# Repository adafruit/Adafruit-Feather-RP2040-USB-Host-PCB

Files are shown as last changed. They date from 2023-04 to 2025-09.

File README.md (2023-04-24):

## Adafruit Feather RP2040 with USB Host PCB

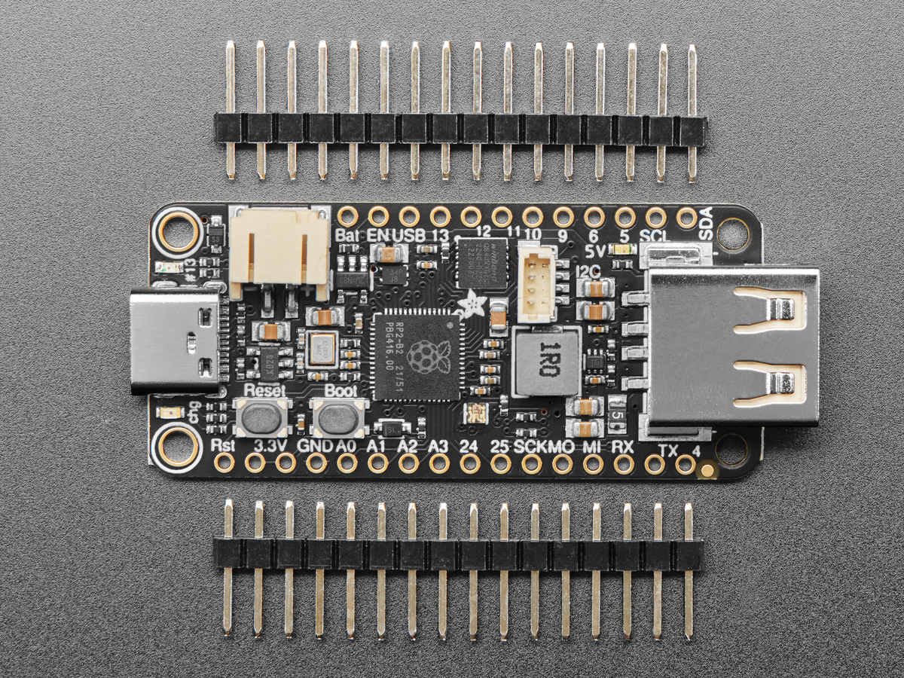
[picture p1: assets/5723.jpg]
<a href="http://www.adafruit.com/products/5723"><br/>
Click here to purchase one from the Adafruit shop</a>

PCB files for the Adafruit Feather RP2040 with USB Host. 

Format is EagleCAD schematic and board layout
* https://www.adafruit.com/product/5723

### Description

You're probably really used to microcontroller boards with USB, but what about a dev board with two? Two is more than one, so that makes it twice as good! And the Adafruit Feather RP2040 with USB Host is definitely double-the-fun of our other Feather RP2040 boards, with a USB Type A port on the end for connecting USB devices to. 

Now you might be thinking "hey waitaminute, the RP2040 doesn't have two USB port peripherals???" and you'd be correct! But what it does have is a nifty PIO peripheral that can be (ab)used to emulate a USB host peripheral. You get to keep the main USB port for uploading, debugging, and data communication, while at the same time sending and receiving data to just-about-any USB device. [This work is originally by sekigon on GitHub](https://github.com/sekigon-gonnoc/Pico-PIO-USB), and if you're using Pico SDK that's still the recommended library to use.

Currently, support for the USB Host peripheral is only in Arduino. So check out the [TinyUSB 'dual role' examples](https://github.com/adafruit/Adafruit_TinyUSB_Arduino/tree/master/examples/DualRole) for some things you can do! For example, [datalogging to a USB Key](https://github.com/adafruit/Adafruit_TinyUSB_Arduino/tree/master/examples/DualRole/MassStorage/msc_data_logger). Or [reading from another device/microcontroller that has USB CDC serial interface](https://github.com/adafruit/Adafruit_TinyUSB_Arduino/tree/master/examples/DualRole/CDC/serial_host_bridge). Or [creating an HID re-mapper](https://github.com/adafruit/Adafruit_TinyUSB_Arduino/tree/master/examples/DualRole/HID/hid_remapper). Or [connecting to weird devices that require firmware-updates like the Cypress EZ-USB based Intellikeys](https://github.com/adafruit/Adafruit_IntelliKeys) communications board.

Note that this is definitely a firmware hack: you will need to dedicate the second ARM core and both PIO peripherals to just handling the USB messages, but we find that it does work fairly well, or at least as well as most microcontroller's USB Host peripherals!

We also include a 1 Amp boost converter based on the TPS61023 so you can run from Lipo battery and get a nice clean 5V output for the USB devices. The booster has the enable pin tied to one of the extra GPIO on the RP2040 so power can be manually turned on and off to hard-reset whatever is connected.

At the Feather's heart is an RP2040 chip, clocked at 133 MHz and at 3.3V logic, the same one used in the Raspberry Pi Pico. This chip has a whopping 8MB of onboard QSPI FLASH and 264K of RAM!  There's even room left over for a STEMMA QT connector for plug-and-play of I2C devices!

To make it easy to use for portable projects, we added a connector for any of our 3.7V Lithium polymer batteries and built-in battery charging. You don't need a battery, it will run just fine straight from the USB Type C connector. But, if you do have a battery, you can take it on the go, then plug in the USB to recharge. The Feather will automatically switch over to USB power when it's available.

Here're some handy specs! You get:

* Measures 2.0" x 0.9" x 0.28" (50.8mm x 22.8mm x 7mm) without headers soldered in
* Light as a (large?) feather - 6.3 grams
* RP2040 32-bit Cortex M0+ dual core running at ~133 MHz @ 3.3V logic and power
* 264 KB RAM
* 8 MB SPI FLASH chip for storing files and CircuitPython/MicroPython code storage. No EEPROM
* Tons of GPIO! 21 x GPIO pins with following capabilities:
* Four 12-bit ADCs (one more than Pico)
* Two I2C, Two SPI, and two UART peripherals, we label one for the 'main' interface in standard Feather locations
* 16 x PWM outputs - for servos, LEDs, etc
* Built-in 200mA+ lipoly charger with charging status indicator LED
* Pin #13 red LED for general purpose blinking
* RGB NeoPixel for full-color indication.
* On-board STEMMA QT connector that lets you quickly connect any Qwiic, STEMMA QT or Grove I2C devices with no soldering!
* Both Reset button and Bootloader select button for quick restarts (no unplugging-replugging to relaunch code)
* USB Type C connector lets you access built-in ROM USB bootloader and serial port debugging
* USB Type A connector for USB host capability. D+ on GPIO 16, D- on GPIO 17
* 5V Boost converter, up to 1 Amp peak output for USB peripheral power, with 500mA resettable fuse. Enable on GPIO 18. 
* 3.3V Power/enable pin
* 4 mounting holes
* 12 MHz crystal for perfect timing.
* 3.3V regulator with 500mA peak current output

### License

Adafruit invests time and resources providing this open source design, please support Adafruit and open-source hardware by purchasing products from [Adafruit](https://www.adafruit.com)!

Designed by Limor Fried/Ladyada for Adafruit Industries.

Creative Commons Attribution/Share-Alike, all text above must be included in any redistribution. 
See license.txt for additional details.

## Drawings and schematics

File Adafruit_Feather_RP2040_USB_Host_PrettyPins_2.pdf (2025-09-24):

## Power GND

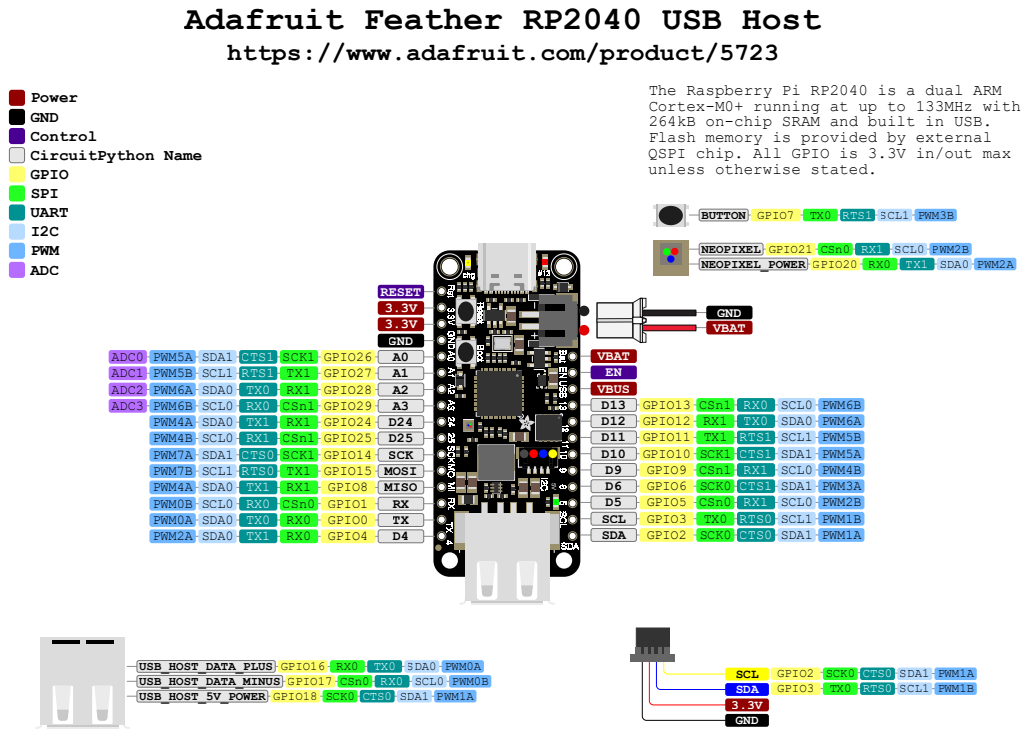
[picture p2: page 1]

Adafruit Feather RP2040 USB Host
https://www.adafruit.com/product/5723

The Raspberry Pi RP2040 is a dual ARM
Cortex-M0+ running at up to 133MHz with
264kB on-chip SRAM and built in USB.
Flash memory is provided by external
QSPI chip. All GPIO is 3.3V in/out max
unless otherwise stated.

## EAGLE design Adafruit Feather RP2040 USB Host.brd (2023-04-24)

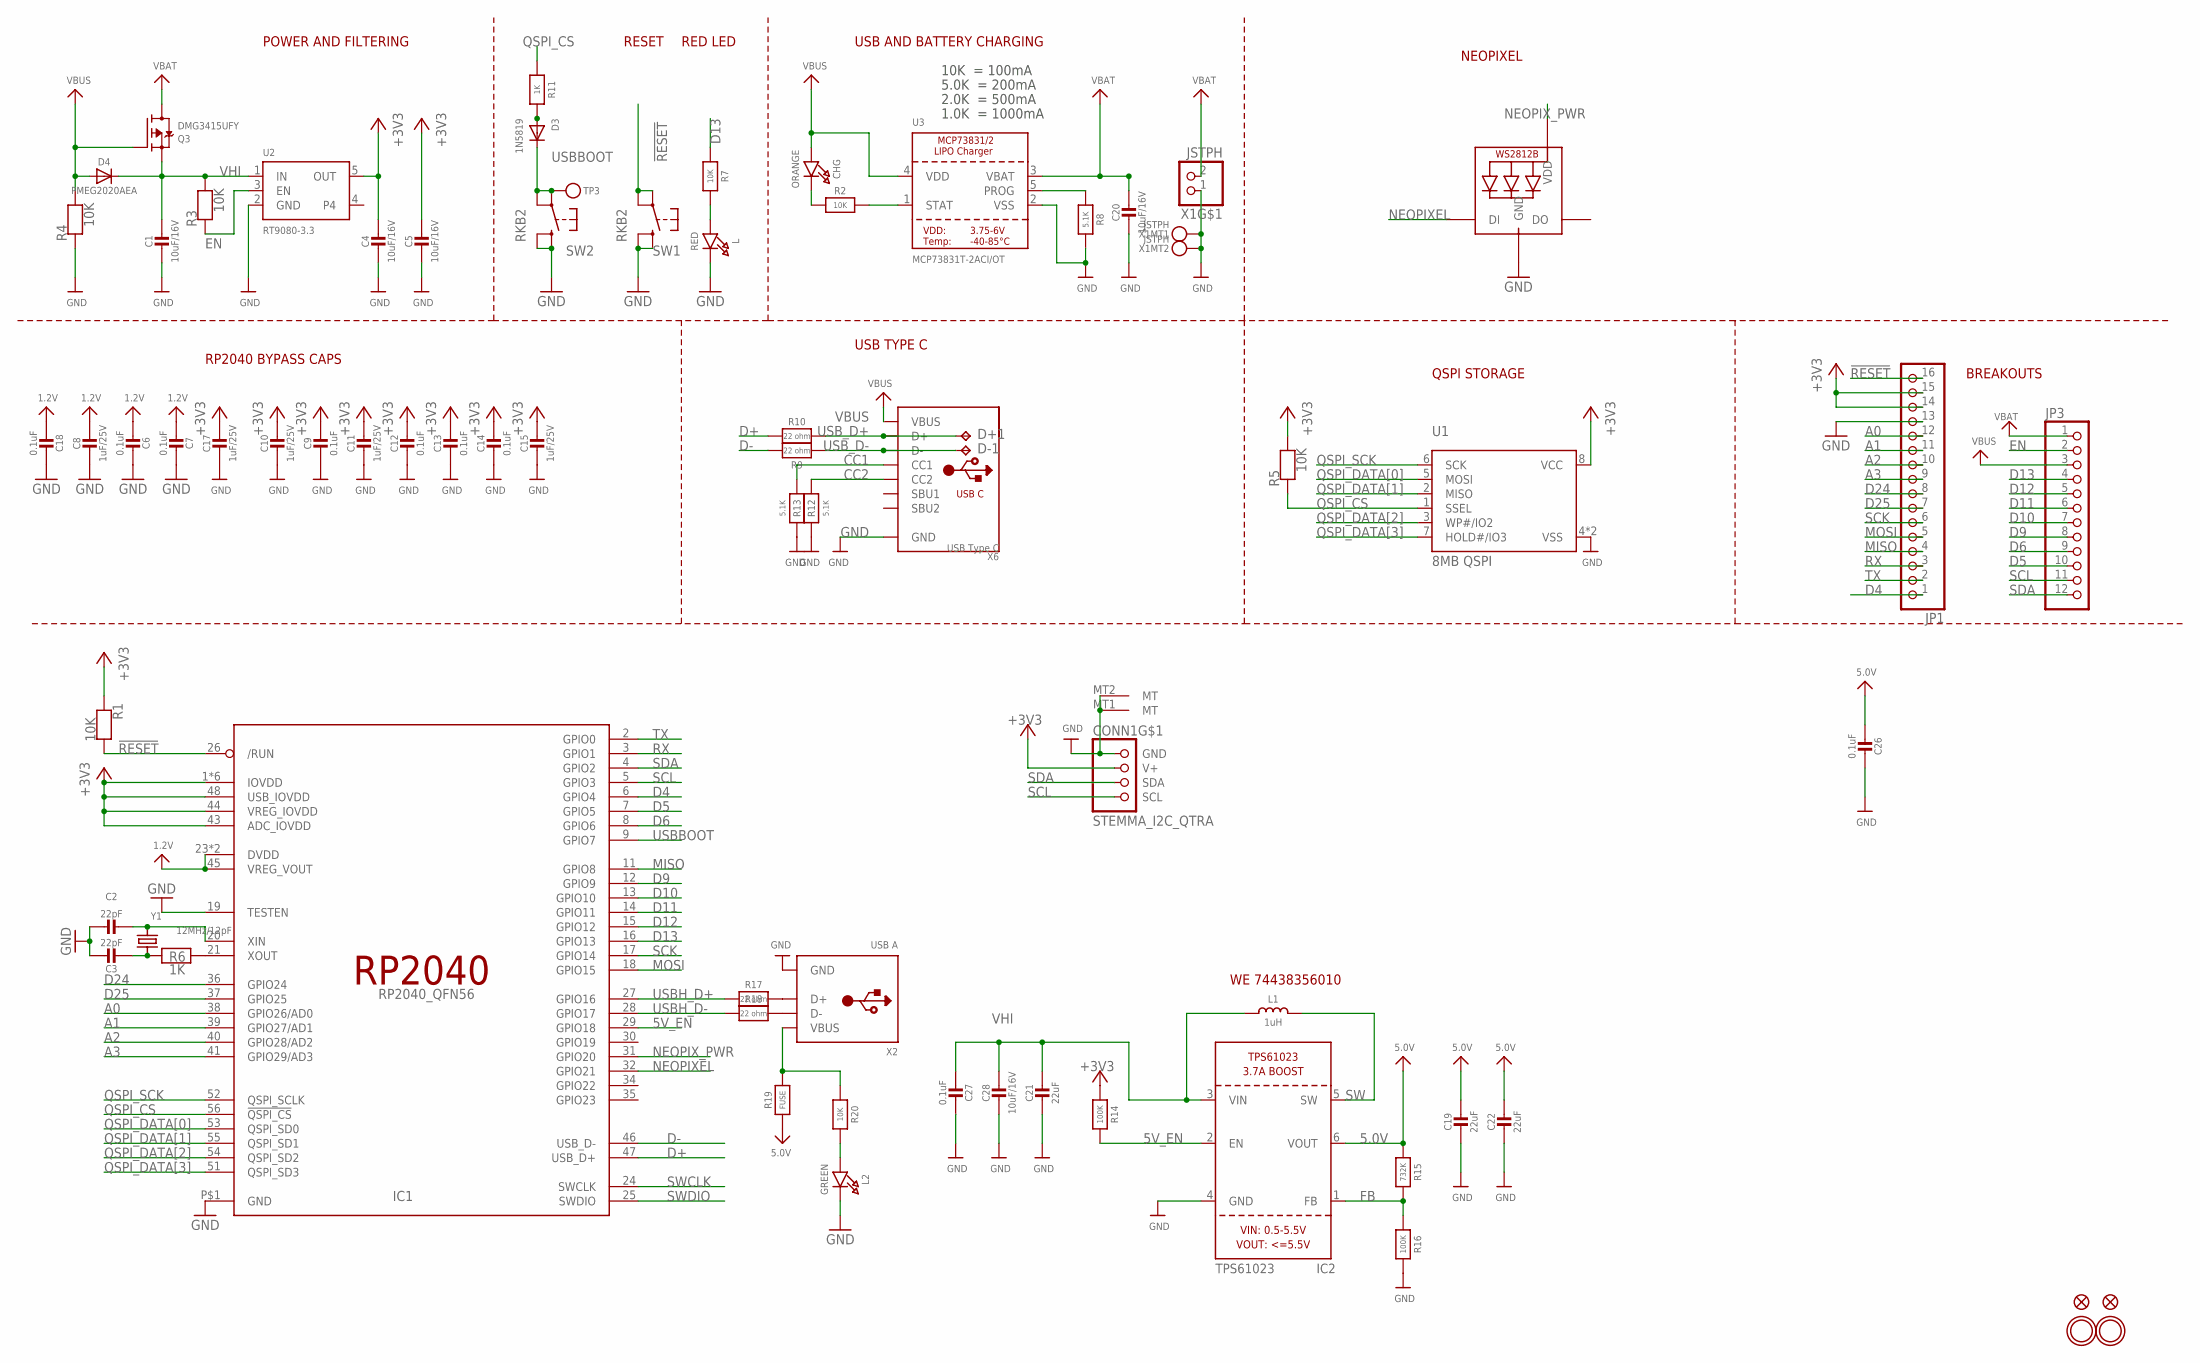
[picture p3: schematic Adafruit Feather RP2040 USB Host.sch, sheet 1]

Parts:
C1, C4, C5, C20, C28: 10uF/16V; 0805-NO
C2, C3: 22pF; _0402NO
C6, C7, C9, C12, C13, C14, C18, C26, C27: 0.1uF; _0402NO
C8, C10, C11, C15, C17: 1uF/25V; _0402NO
C19, C21, C22: 22uF; 0805-NO
CHG: ORANGE; CHIPLED_0603_NOOUTLINE
CONN1: STEMMA_I2C_QTRA; JST_SH4_RA
D3: 1N5819; SOD-323_MINI
D4: PMEG2020AEA; SOD-323F
D+1: TPB1,27; B1,27
D-1: TPB1,27; B1,27
IC1: RP2040_QFN56; QFN56_7MM_REDUCEDEPAD
IC2: TPS61023; SOT563
JP1: HEADER-1X16ROUND; 1X16_ROUND
JP3: HEADER-1X12; 1X12_ROUND
L: RED; CHIPLED_0603_NOOUTLINE
L1: 1uH; INDUCTOR_5045_SMALLTABS
L2: GREEN; CHIPLED_0603_NOOUTLINE
LED1: WS2812B_SK6805_1515; SK6805_1515
Q3: DMG3415UFY; DFN2015-3
R1, R2, R3, R4, R5, R7, R20: 10K; _0402NO
R6, R11: 1K; _0402NO
R8, R12, R13: 5.1K; _0402NO
R9, R10, R17, R18: 22 ohm; _0402NO
R14, R16: 100K; _0402NO
R15: 732K; _0402NO
R19: FUSE; 0805-NO
SW1, SW2: RKB2; BTN_RKB2_4.6X2.8
TP3: TESTPOINTROUND1.5MMNO; TESTPOINT_ROUND_1.5MM_NO
U1: 8MB QSPI; USON8_4X4
U2: RT9080-3.3; SOT23-5; JLC_ROTATION 0
U3: MCP73831T-2ACI/OT; SOT23-5
U$31, U$32: MOUNTINGHOLE2.5; MOUNTINGHOLE_2.5_PLATED
U$34, U$35: FIDUCIAL_1MM
X1: JSTPH; JSTPH2_BATT
X2: USB A; USB_HOST-SMT
X6: USB Type C; USB_C_CUSB31-CFM2AX-01-X
Y1: 12MHz/12pF; CRYSTAL_2.5X2

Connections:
1.2V: C6.2, C7.2, C8.1, C18.2, IC1.23 (DVDD), IC1.45 (VREG_VOUT), IC1.50 (DVDD)
5.0V: C19.1, C22.1, C26.2, IC2.6 (VOUT), R15.1, R19.2
5V_EN: IC1.29 (GPIO18), IC2.2 (EN), R14.2
!RESET: IC1.26 (/RUN), JP1.16, R1.2, SW1.A, SW1.A' (P1)
+3V3: C4.1, C5.1, C9.1, C10.1, C11.1, C12.1, C13.1, C14.1, C15.1, C17.1, CONN1.2 (V+), IC1.1 (IOVDD), IC1.10 (IOVDD), IC1.22 (IOVDD), IC1.33 (IOVDD), IC1.42 (IOVDD), IC1.43 (ADC_IOVDD), IC1.44 (VREG_IOVDD), IC1.48 (USB_IOVDD), IC1.49 (IOVDD), JP1.14, JP1.15, R1.1, R5.2, R14.1, U1.8 (VCC), U2.5 (OUT)
A0: IC1.38 (GPIO26/AD0), JP1.12
A1: IC1.39 (GPIO27/AD1), JP1.11
A2: IC1.40 (GPIO28/AD2), JP1.10
A3: IC1.41 (GPIO29/AD3), JP1.9
CC1: R13.2, X6.A5 (CC1)
CC2: R12.2, X6.B5 (CC2)
D4: IC1.6 (GPIO4), JP1.1
D5: IC1.7 (GPIO5), JP3.10
D6: IC1.8 (GPIO6), JP3.9
D9: IC1.12 (GPIO9), JP3.8
D10: IC1.13 (GPIO10), JP3.7
D11: IC1.14 (GPIO11), JP3.6
D12: IC1.15 (GPIO12), JP3.5
D13: IC1.16 (GPIO13), JP3.4, R7.1
D24: IC1.36 (GPIO24), JP1.8
D25: IC1.37 (GPIO25), JP1.7
D+: IC1.47 (USB_D+), R10.2
D-: IC1.46 (USB_D-), R9.2
EN: JP3.2, R3.1, U2.3 (EN)
FB: IC2.1 (FB), R15.2, R16.1
GND: C1.2, C2.1, C3.1, C4.2, C5.2, C6.1, C7.1, C8.2, C9.2, C10.2, C11.2, C12.2, C13.2, C14.2, C15.2, C17.2, C18.1, C19.2, C20.2, C21.2, C22.2, C26.1, C27.1, C28.2, CONN1.1 (GND), CONN1.MT1 (MT), CONN1.MT2 (MT), IC1.19 (TESTEN), IC1.P$1 (GND), IC2.4 (GND), JP1.13, L.C, L2.C, LED1.4 (GND), R4.1, R8.2, R12.1, R13.1, R16.2, SW1.B (S), SW1.B' (S1), SW2.B (S), SW2.B' (S1), U1.4 (VSS), U1.PAD (VSS), U2.2 (GND), U3.2 (VSS), X1.1, X1.NC1, X1.NC2, X2.GND, X6.A1B12 (GND), X6.B1A12 (GND)
MISO: IC1.11 (GPIO8), JP1.4
MOSI: IC1.18 (GPIO15), JP1.5
unnamed: CHG.C, R2.1
unnamed: L.A, R7.2
unnamed: R2.2, U3.1 (STAT)
unnamed: R8.1, U3.5 (PROG)
unnamed: C2.2, IC1.20 (XIN), Y1.3 (2)
unnamed: C3.2, R6.1, Y1.1
unnamed: IC1.21 (XOUT), R6.2
unnamed: R17.1, X2.D+
unnamed: R18.1, X2.D-
unnamed: R19.1, R20.1, X2.VBUS
unnamed: L2.A, R20.2
unnamed: D3.A, R11.2
NEOPIXEL: IC1.32 (GPIO21), LED1.1 (DI)
NEOPIX_PWR: IC1.31 (GPIO20), LED1.2 (VDD)
QSPI_CS: IC1.56 (!QSPI_CS), R5.1, R11.1, U1.1 (SSEL)
QSPI_DATA[0]: IC1.53 (QSPI_SD0), U1.5 (MOSI)
QSPI_DATA[1]: IC1.55 (QSPI_SD1), U1.2 (MISO)
QSPI_DATA[2]: IC1.54 (QSPI_SD2), U1.3 (WP#/IO2)
QSPI_DATA[3]: IC1.51 (QSPI_SD3), U1.7 (HOLD#/IO3)
QSPI_SCK: IC1.52 (QSPI_SCLK), U1.6 (SCK)
RX: IC1.3 (GPIO1), JP1.3
SCK: IC1.17 (GPIO14), JP1.6
SCL: CONN1.4 (SCL), IC1.5 (GPIO3), JP3.11
SDA: CONN1.3 (SDA), IC1.4 (GPIO2), JP3.12
SW: IC2.5 (SW), L1.2
SWCLK: IC1.24 (SWCLK)
SWDIO: IC1.25 (SWDIO)
TX: IC1.2 (GPIO0), JP1.2
USBBOOT: D3.C, IC1.9 (GPIO7), SW2.A, SW2.A' (P1), TP3.P$1
USBH_D+: IC1.27 (GPIO16), R17.2
USBH_D-: IC1.28 (GPIO17), R18.2
USB_D+: D+1.TP, R10.1, X6.A6 (D+), X6.B6 (D+)
USB_D-: D-1.TP, R9.1, X6.A7 (D-), X6.B7 (D-)
VBAT: C20.1, JP3.1, Q3.3 (D), U3.3 (VBAT), X1.2
VBUS: CHG.A, D4.A, JP3.3, Q3.1 (G), R4.2, U3.4 (VDD), X6.A4B9 (VBUS), X6.B4A9 (VBUS)
VHI: C1.1, C21.1, C27.2, C28.1, D4.C, IC2.3 (VIN), L1.1, Q3.2 (S), R3.2, U2.1 (IN)

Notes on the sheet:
POWER AND FILTERING
RESET
10K = 100mA
5.0K = 200mA
2.0K = 500mA
1.0K = 1000mA
USB AND BATTERY CHARGING
BREAKOUTS
RED LED
RP2040 BYPASS CAPS
USB TYPE C
QSPI STORAGE
NEOPIXEL
WE 74438356010

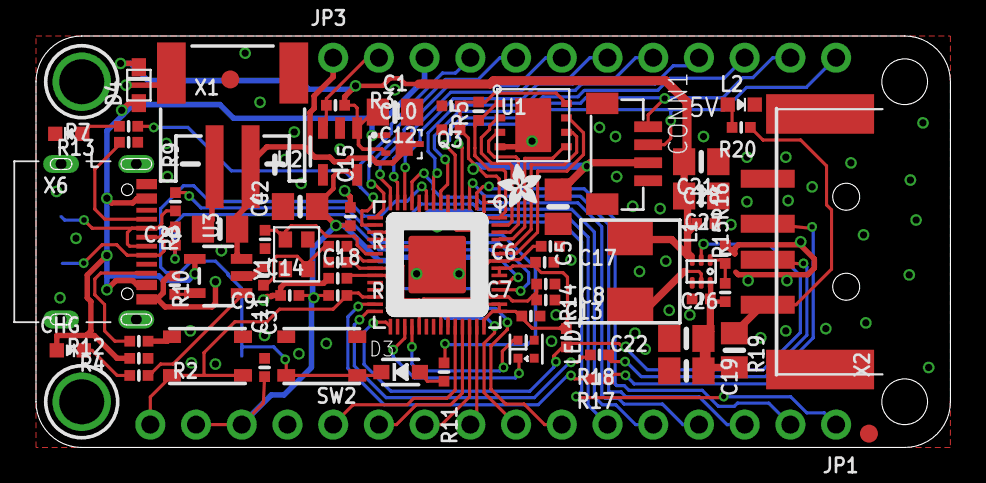
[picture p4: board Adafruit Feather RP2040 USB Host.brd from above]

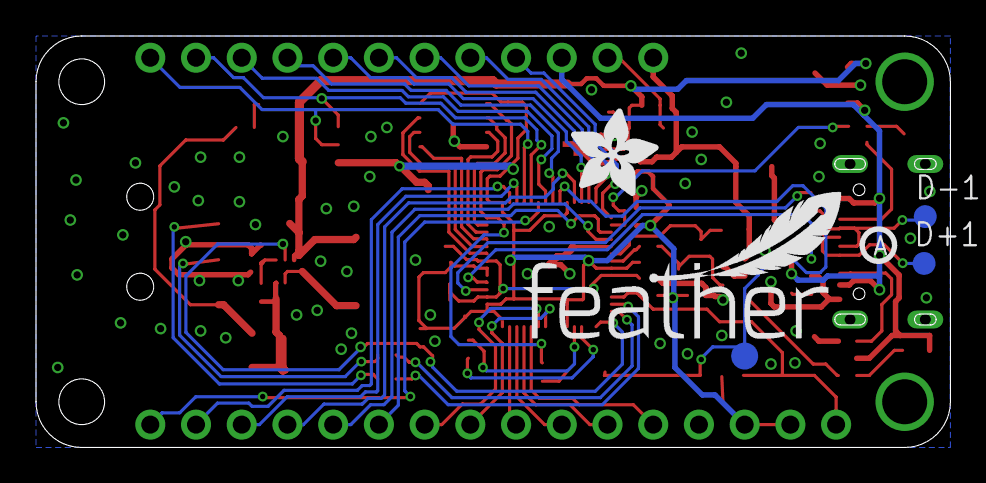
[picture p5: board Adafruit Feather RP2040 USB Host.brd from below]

Board: 2 copper layers, 50.8 x 22.9 mm, 140 parts (37 on the bottom side), 62 nets.

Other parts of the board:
PLABEL0: PLABEL0
PLABEL1: PLABEL1
PLABEL2: PLABEL2
PLABEL3: PLABEL3
PLABEL4: PLABEL4
PLABEL5: PLABEL5
PLABEL6: PLABEL6
PLABEL7: PLABEL7
PLABEL8: PLABEL8
PLABEL9: PLABEL9
PLABEL10: PLABEL10
PLABEL11: PLABEL11
PLABEL12: PLABEL12
PLABEL13: PLABEL13
PLABEL14: PLABEL14
PLABEL15: PLABEL15
PLABEL16: PLABEL16
PLABEL17: PLABEL17
PLABEL18: PLABEL18
PLABEL19: PLABEL19
PLABEL20: PLABEL20
PLABEL21: PLABEL21
PLABEL22: PLABEL22
PLABEL23: PLABEL23
PLABEL24: PLABEL24
PLABEL25: PLABEL25
PLABEL26: PLABEL26
PLABEL27: PLABEL27
PLABEL28: PLABEL28
PLABEL29: PLABEL29
PLABEL30: PLABEL30
PLABEL31: PLABEL31
PLABEL32: PLABEL32
PLABEL33: PLABEL33
PLABEL34: PLABEL34
PLABEL35: PLABEL35
PLABEL36: PLABEL36
PLABEL37: PLABEL37
PLABEL38: PLABEL38
PLABEL39: PLABEL39
PLABEL40: PLABEL40
PLABEL41: PLABEL41
PLABEL42: PLABEL42
PLABEL43: PLABEL43
PLABEL44: PLABEL44
PLABEL45: PLABEL45
PLABEL46: PLABEL46
PLABEL47: PLABEL47
PLABEL48: PLABEL48
PLABEL49: PLABEL49
PLABEL50: PLABEL50
PLABEL51: PLABEL51
PLABEL52: PLABEL52
PLABEL53: PLABEL53
PLABEL54: PLABEL54
PLABEL55: PLABEL55
PLABEL56: PLABEL56
PLABEL57: PLABEL57
PLABEL58: PLABEL58
PLABEL59: PLABEL59
PLABEL60: PLABEL60
PLABEL61: PLABEL61
PLABEL62: PLABEL62
U$13: PCBFEAT-REV-040
U$43: ADAFRUIT_2.5MM
U$46: FEATHERLOGO_MED
U$47: ADAFRUIT_5MM

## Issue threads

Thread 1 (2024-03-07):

its been a week and i still cant get any example code to work.

dosuserx, 2024-03-07:
im not even sure what im doing wrong. all i know is that while i can upload code to the rp2040 usb host feather fine, after i have done so i cannot get the serial monitor to work. i tried using putty, but for some reason i have like 21 unnamed usb com ports. arduino 2 app will not recognize a port nor will windows name the port. i mainly just want to make a code that powers a usb type b midi device and transports the midi code to the usb c port. all the tutorials are written for older versions of windows and arduino. basically nothing is written about this board online. barely anything. does anyone have a suggestion of where to start with this board?

BlitzCityDIY, 2024-03-11:
hihi- sorry you've been having problems. we recommend going to the forums for support questions like this for a quick response and troubleshooting assistance: https://forums.adafruit.com/viewforum.php?f=57

i was able to recreate your problems after updating the Philhower core. To resolve it, I closed out of the Arduino IDE, navigated to the Arduino packages folder on Windows (C:\Users\[username]\AppData\Local\Arduino15\packages), deleted the rp2040 folder, reopened the Arduino IDE and installed the Philhower core so that it was a fresh install. After that, I uploaded the code to the board and was able to use the USB host simple example from TinyUSB and see device info.

i have not tested with the Arduino 2 IDE yet, so I would also recommend using version 1 to see if that solves the problem. if you are still unable to upload code to the board after trying these two ideas please post to the forums.

dosuserx, 2024-03-11:
> hihi- sorry you've been having problems. we recommend going to the forums for support questions like this for a quick response and troubleshooting assistance: https://forums.adafruit.com/viewforum.php?f=57

is that not what i did? sorry if i posted this in the wrong place. ive never tried to get tech support like this before and i find it confusing. thank you for your assistance. ill try these things.

dosuserx, 2024-03-11:
yeah, it doesn't seem to work on either versions of arduino. or at least the older version of arduino has the same results as using arduino 2.

caternuson, 2024-03-11:
Adding forum post for tie in:
https://forums.adafruit.com/viewtopic.php?t=209070

dosuserx, 2024-03-12:
thank you. i have no idea what im doing. the arduino stuff i understand, but forum etiquette i guess not.

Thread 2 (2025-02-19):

Clean schematic of RP2040 feather USB A Host?  The JPG on the adafruit page is barely readable.

MackNNations, 2025-02-19:
I would like to request a clean, readable, preferably pdf format schematic of the RP2040 feather USB A Host board, please.

Thank you.

tannewt, 2025-02-20:
Product learn guides have images of the schematic in their Downloads section: https://learn.adafruit.com/adafruit-feather-rp2040-with-usb-type-a-host/downloads

Closed 2025-02-20.

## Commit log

2023-04-24 adding cookiecutter output
    [Adafruit Feather RP2040 USB Host.brd, Adafruit Feather RP2040 USB Host.sch]
2025-09-24 Change battery connector to correct view

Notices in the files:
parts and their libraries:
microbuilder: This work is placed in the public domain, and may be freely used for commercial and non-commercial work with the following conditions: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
